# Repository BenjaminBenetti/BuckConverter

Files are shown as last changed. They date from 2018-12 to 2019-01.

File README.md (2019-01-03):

# BuckConverter
Home made buck converter with Arduino. Can provide switching between 0-30v (cannot provide more voltage than input source). Max input power is 30v. If not external
power is supplied (through Arduino USB jack) minimum voltage of 6 volts required to power Arduino. Max amperage is unknown
but be careful as this unit can get very hot (no joke it can burn down your house). any thing under 2 amps ought to be ok.

## Hardware Requirments
  - 3d Printer, to build the case.
  - 1x 7 segment 4 digit display
  - 1x Arduino nano (any Atmega 48P/88P/168P or 328P AVR MCU)
  - 1x inductor
  - 1x 1000 uF capacitor
  - 1x P type Mosfet
  - 5x NPN transistor
  - 2x tact switch
  - 1x diode
  - 2x 10k Ohm  resistor
  - 4x 5.1k Ohm resistor
  - 1x 2K Ohm   resistor
  - 1x 1K Ohm   resistor
  - 2x 330 Ohm  resistor
  - 1x 100 Ohm  resistor

## Hardware Build

with all the hardware in hand you should be able to build the circuits in the /Hardware folder:
- [Buck Converter circuit](https://github.com/CanadianCommander/BuckConverter/blob/master/Hardware/BuckConverterCircuit.pdf)
- [User Interface circuit](https://github.com/CanadianCommander/BuckConverter/blob/master/Hardware/UserInterfaceCircuit.pdf)

After that print out the case with:
- [Case Top](https://github.com/CanadianCommander/BuckConverter/blob/master/Hardware/BuckConverterTop.stl)
- [Case Bottom](https://github.com/CanadianCommander/BuckConverter/blob/master/Hardware/BuckConverterBottom.stl)

Now sandwich all the electronics in to the case and you should end up with some thing similar to [this](https://github.com/CanadianCommander/BuckConverter/blob/master/Hardware/BuckConverterFull.stl)

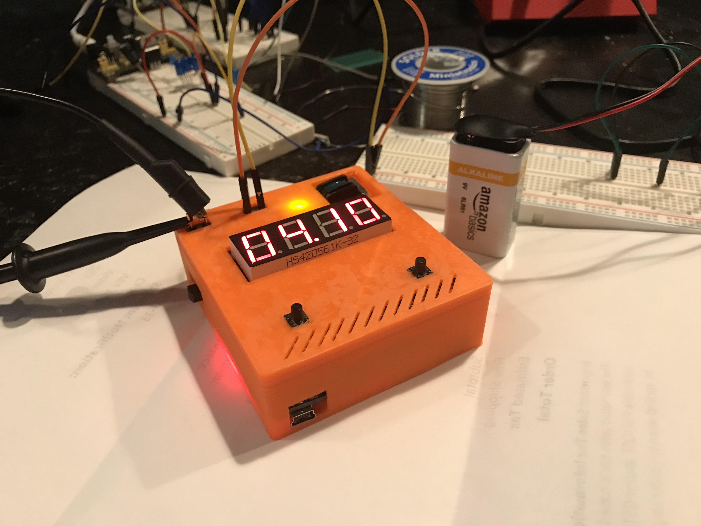
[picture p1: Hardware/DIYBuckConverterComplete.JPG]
DYI Buck Converter


## Code Build
- download repo.
- install [arduion make](https://github.com/sudar/Arduino-Makefile)
- if necessary edit the Makefile (/src/Makefile) to reflect your configuration
- then `make upload` to build and upload the code to your board.
- enjoy your buck converter!

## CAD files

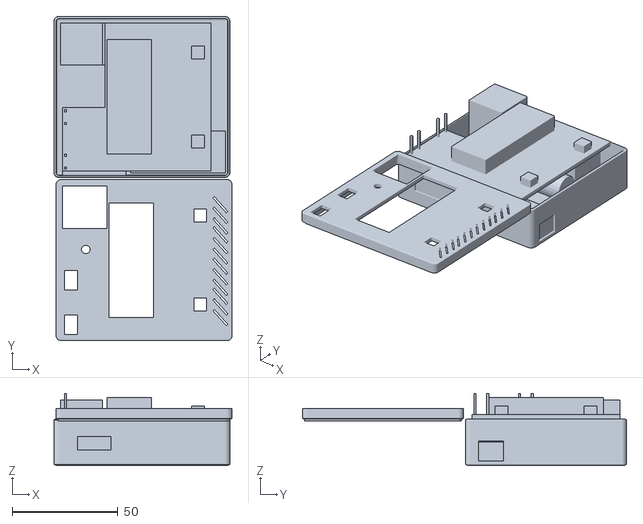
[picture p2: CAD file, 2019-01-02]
Hardware/BuckConverterFull.stl
84.0 x 153.0 x 34.0

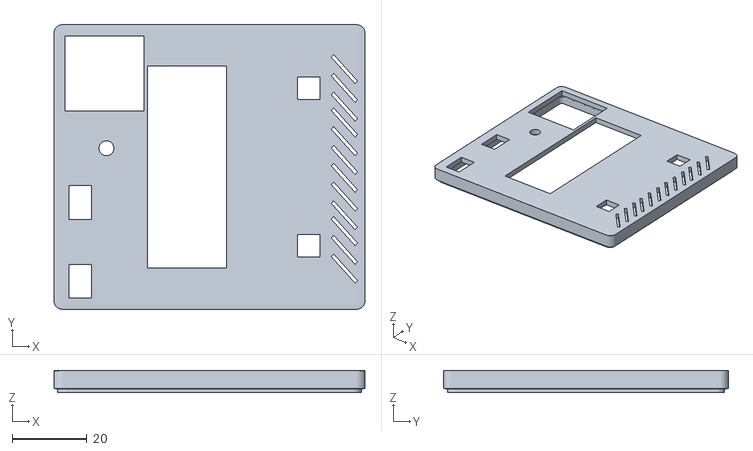
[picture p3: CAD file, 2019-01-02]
Hardware/BuckConverterTop.stl
83.0 x 76.0 x 6.00

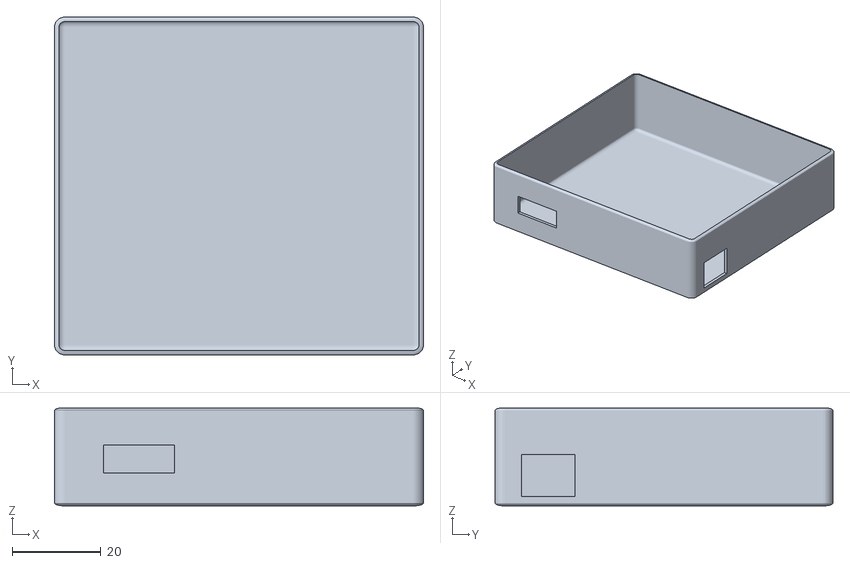
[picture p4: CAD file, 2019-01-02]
Hardware/BuckConverterBottom.stl
83.0 x 76.0 x 22.0

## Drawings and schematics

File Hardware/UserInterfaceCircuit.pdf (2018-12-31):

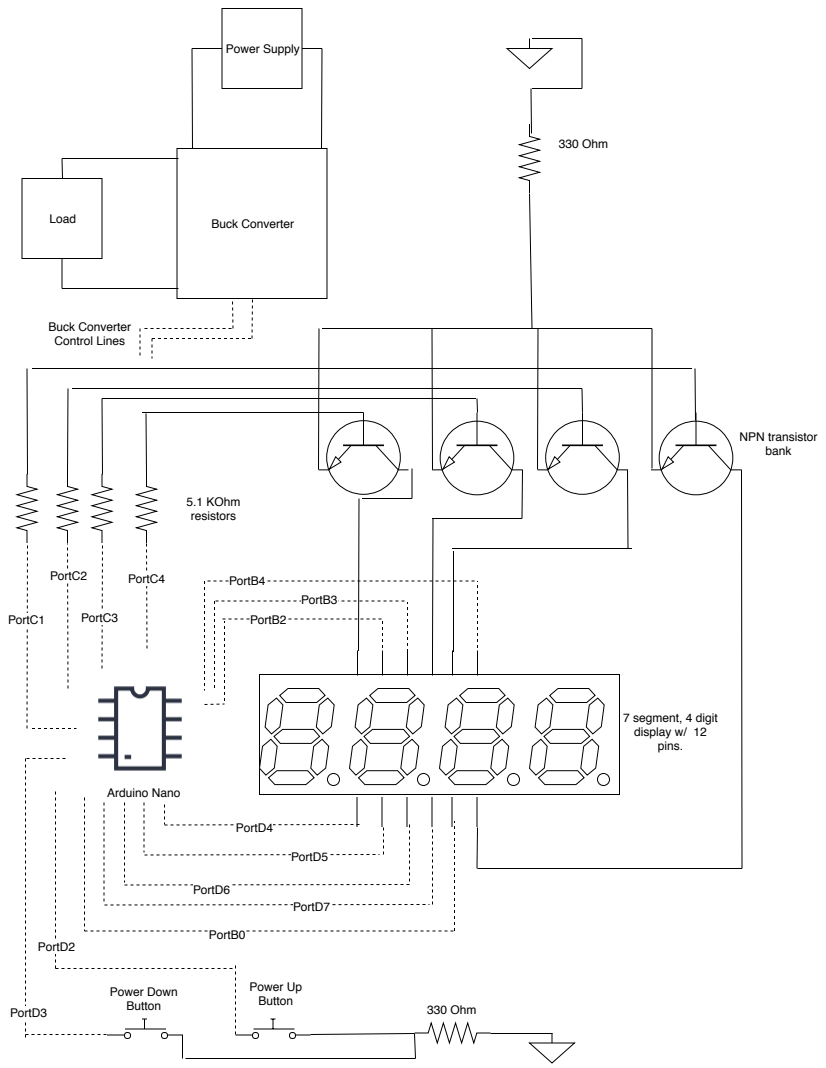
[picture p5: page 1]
Buck Converter; Power Supply; Load; Buck Converter Control Lines; Arduino Nano; PortD4; PortD5; PortD6; PortD7; PortB0; PortB2; PortB3; PortB4; NPN transistor bank; 330 Ohm; 5.1 KOhm resistors; 7 segment, 4 digit display w/ 12 pins.; PortC1; PortC2; PortC3; PortC4; Power Down Button; Power Up Button; PortD2; PortD3

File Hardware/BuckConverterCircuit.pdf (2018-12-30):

+ | -

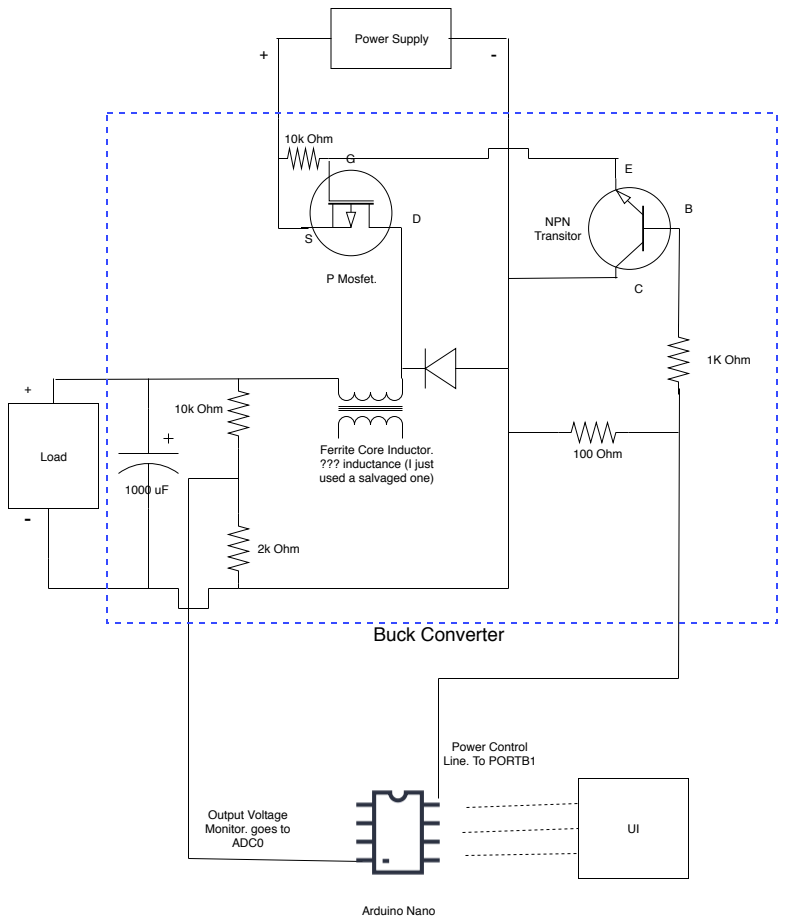
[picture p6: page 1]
P Mosfet.; 10k Ohm; Load; Power Supply; Arduino Nano; 2k Ohm; 1K Ohm; 100 Ohm; Power Control Line. To PORTB1; Buck Converter; NPN Transitor

Ferrite Core Inductor.
??? inductance (I just
used a salvaged one)

Output Voltage
Monitor. goes to
ADC0

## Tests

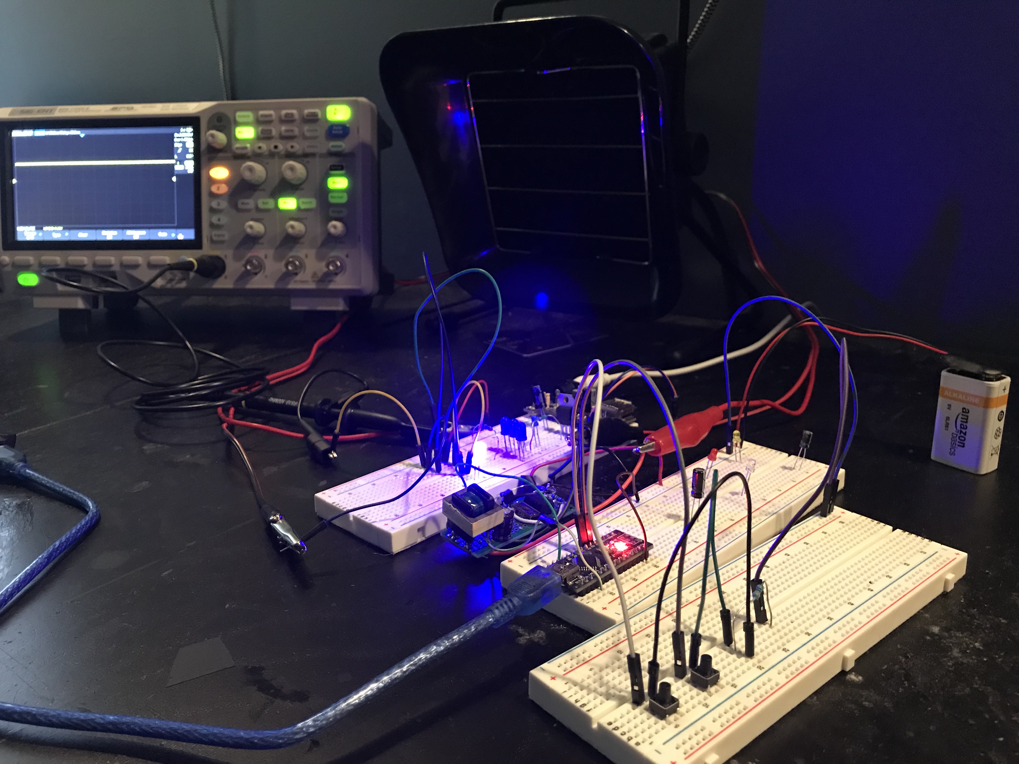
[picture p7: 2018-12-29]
Hardware/testing_the_unit.JPG

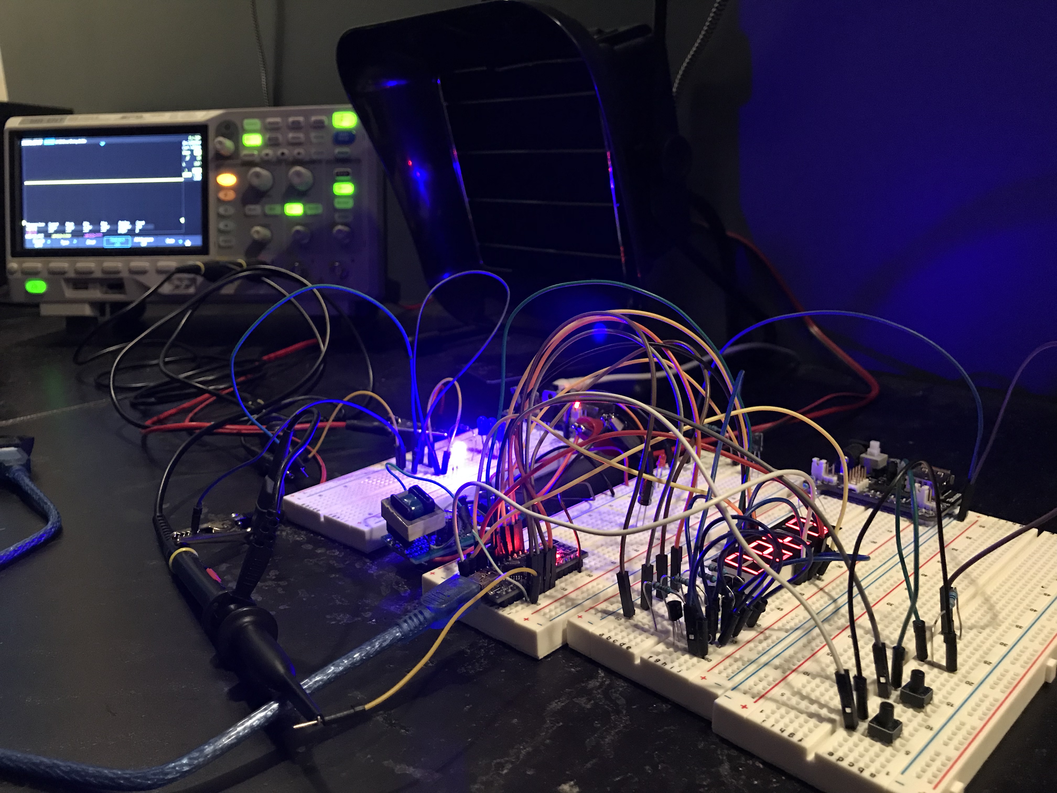
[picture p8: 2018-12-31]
Hardware/testing_uint_with_display.JPG

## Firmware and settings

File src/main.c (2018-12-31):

#include <avr/io.h>
#include <avr/interrupt.h>
#include <stdint.h>
#include <stdbool.h>
#include <string.h>
#include <math.h>

#include "ADC.h"
#include "PWM.h"
#include "UI.h"
#include "EEPROM.h"
#include "display.h"

#define PWR_TARGET_EEPROM_ADDR 1
#define PWR_TARGET_EEPROM_MARKER 0b11101010

// find the address of the power target in EEPROM.
uint16_t findPowerTargetInEEPROM(){
  uint16_t addr = searchEEPROM(PWR_TARGET_EEPROM_MARKER, 1, EEPROM_SIZE);
  if (addr == 0){
    return 1;
  }
  return addr;
}

//save power target to EEPROM at a rolling address to extend EEPROM life.
// minimum EEPROM life with the rotation method is 15,000,000 writes. (button presses in this case).
uint16_t savePowerTarget(uint16_t pwrTarget, uint16_t addr){
  uint16_t newAddr = (addr + 3) % (EEPROM_SIZE - 3);
  if (newAddr == 0) {
    newAddr ++;
  }
  //clear old address
  clearEEPROM(0, 3, addr);

  //write to new address
  uint8_t marker = PWR_TARGET_EEPROM_MARKER;
  writeEEPROM(&marker, 1, newAddr);
  writeEEPROM((uint8_t*)&pwrTarget, 2, newAddr + 1);

  return newAddr;
}

//load power target from EEPROM
uint16_t loadPowerTarget(uint16_t addr){
  uint16_t out;
  readEEPROM((uint8_t*)&out, 2, addr + 1);
  return out;
}

uint16_t calcPWMUpdate(uint16_t v, uint16_t vt){
  // "always 1" seems the best method of the ones I'v tried. perhaps some thing better
  // here in the future?
  return 1;
}

void updateDisplay();

// display vars
uint8_t displayDigits[4];
int displayIndex = 0;

// power regulation vars
uint16_t currPWM = 0;
uint16_t oldPowerTarget = 0;

uint16_t pwrTargetStorageAddress = 0;

// calculated based on voltage divider circuit
#define VOLTAGE_DIVIDER_COMPENSATION_VALUE 30.0f

void checkNSwitch() {
  uint16_t currVoltage = getADCSample();
  uint16_t currTarget = getPowerTarget();

  // update display and save new value if power target has changed.
  if (currTarget != oldPowerTarget) {
    oldPowerTarget = currTarget;
    pwrTargetStorageAddress = savePowerTarget(currTarget, pwrTargetStorageAddress);
    numToSegmentList(displayDigits, VOLTAGE_DIVIDER_COMPENSATION_VALUE * ((float)getPowerTarget() / 1024.0f), -2);
  }

  if (currVoltage < currTarget) {
    uint16_t update = calcPWMUpdate(currVoltage, currTarget);
    if (currPWM + update <= 0x3ff){
      currPWM += update;
    } else {
      currPWM = 0x3ff;
    }
    setDutyCycle(currPWM);
  } else {
    uint16_t update = calcPWMUpdate(currVoltage, currTarget);
    if ((int)currPWM - (int)update >= 0){
      currPWM -= update;
    } else {
      currPWM = 0;
    }
    setDutyCycle(currPWM);
  }
  updateDisplay();
}

void updateDisplay(){
    clearAllSegments();
    setDigit(displayIndex);
    setSegment(displayDigits[displayIndex]);
    displayIndex = (displayIndex + 1) % 4;
}

void setup() {
  initADC();
  initPWM();
  initUI();
  initDisplay();
  if (!isEEPROMContentValid()){
    initEEPROM();
  }

  sampleADCFreeRun(0x0);
  pwrTargetStorageAddress = findPowerTargetInEEPROM();
  oldPowerTarget = loadPowerTarget(pwrTargetStorageAddress);
  setPowerTarget(oldPowerTarget);
  numToSegmentList(displayDigits, VOLTAGE_DIVIDER_COMPENSATION_VALUE * ((float)getPowerTarget() / 1024.0f), -2);

  sei();
}

void loop(){
  checkNSwitch();
}

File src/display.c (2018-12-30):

#include "display.h"

#include <avr/io.h>
#include <math.h>
#include <stdlib.h>

// seven segment display setters
#define SET_DISPLAY_E()   PORTD |= (1 << PORTD4)
#define SET_DISPLAY_D()   PORTD |= (1 << PORTD5)
#define SET_DISPLAY_DP()  PORTD |= (1 << PORTD6)
#define SET_DISPLAY_C()   PORTD |= (1 << PORTD7)
#define SET_DISPLAY_G()   PORTB |= (1 << PORTB0)
#define SET_DISPLAY_A()   PORTB |= (1 << PORTB2)
#define SET_DISPLAY_F()   PORTB |= (1 << PORTB3)
#define SET_DISPLAY_B()   PORTB |= (1 << PORTB4)
#define CLEAR_DISPLAY_E()   PORTD &= ~(1 << PORTD4)
#define CLEAR_DISPLAY_D()   PORTD &= ~(1 << PORTD5)
#define CLEAR_DISPLAY_DP()  PORTD &= ~(1 << PORTD6)
#define CLEAR_DISPLAY_C()   PORTD &= ~(1 << PORTD7)
#define CLEAR_DISPLAY_G()   PORTB &= ~(1 << PORTB0)
#define CLEAR_DISPLAY_A()   PORTB &= ~(1 << PORTB2)
#define CLEAR_DISPLAY_F()   PORTB &= ~(1 << PORTB3)
#define CLEAR_DISPLAY_B()   PORTB &= ~(1 << PORTB4)

// seven segment display enablers
#define ENABLE_DISPLAY_E()   DDRD |= (1 << PORTD4)
#define ENABLE_DISPLAY_D()   DDRD |= (1 << PORTD5)
#define ENABLE_DISPLAY_DP()  DDRD |= (1 << PORTD6)
#define ENABLE_DISPLAY_C()   DDRD |= (1 << PORTD7)
#define ENABLE_DISPLAY_G()   DDRB |= (1 << PORTB0)
#define ENABLE_DISPLAY_A()   DDRB |= (1 << PORTB2)
#define ENABLE_DISPLAY_F()   DDRB |= (1 << PORTB3)
#define ENABLE_DISPLAY_B()   DDRB |= (1 << PORTB4)

//digit selector setters (note, the intentional clear of other digits in each selector)
#define SELECT_DISPLAY_DIG0() PORTC = (1 << PORTC1)
#define SELECT_DISPLAY_DIG1() PORTC = (1 << PORTC2)
#define SELECT_DISPLAY_DIG2() PORTC = (1 << PORTC3)
#define SELECT_DISPLAY_DIG3() PORTC = (1 << PORTC4)

// clear all display digits
#define CLEAR_DISPLAY_DIG_ALL() PORTC = 0x0

// digit selector enablers
#define ENABLE_DISPLAY_DIG0() DDRC |= (1 << PORTC1)
#define ENABLE_DISPLAY_DIG1() DDRC |= (1 << PORTC2)
#define ENABLE_DISPLAY_DIG2() DDRC |= (1 << PORTC3)
#define ENABLE_DISPLAY_DIG3() DDRC |= (1 << PORTC4)

//initialize the 7 segment display
void initDisplay() {
  //segments
  ENABLE_DISPLAY_E();
  ENABLE_DISPLAY_D();
  ENABLE_DISPLAY_DP();
  ENABLE_DISPLAY_C();
  ENABLE_DISPLAY_G();
  ENABLE_DISPLAY_A();
  ENABLE_DISPLAY_F();
  ENABLE_DISPLAY_B();

  //digit selectors
  ENABLE_DISPLAY_DIG0();
  ENABLE_DISPLAY_DIG1();
  ENABLE_DISPLAY_DIG2();
  ENABLE_DISPLAY_DIG3();
}

// set a segment of the 7 segment display.
void setSegment(uint8_t seg){
  if (seg & DISPLAY_A) {
    SET_DISPLAY_A();
  }
  if (seg & DISPLAY_B) {
    SET_DISPLAY_B();
  }
  if (seg & DISPLAY_C) {
    SET_DISPLAY_C();
  }
  if (seg & DISPLAY_D) {
    SET_DISPLAY_D();
  }
  if (seg & DISPLAY_E) {
    SET_DISPLAY_E();
  }
  if (seg & DISPLAY_F) {
    SET_DISPLAY_F();
  }
  if (seg & DISPLAY_G) {
    SET_DISPLAY_G();
  }
  if (seg & DISPLAY_DP) {
    SET_DISPLAY_DP();
  }
}

// clear a segment of the 7 segment display.
void clearSegment(uint8_t seg){
  if (seg & DISPLAY_A) {
    CLEAR_DISPLAY_A();
  }
  if (seg & DISPLAY_B) {
    CLEAR_DISPLAY_B();
  }
  if (seg & DISPLAY_C) {
    CLEAR_DISPLAY_C();
  }
  if (seg & DISPLAY_D) {
    CLEAR_DISPLAY_D();
  }
  if (seg & DISPLAY_E) {
    CLEAR_DISPLAY_E();
  }
  if (seg & DISPLAY_F) {
    CLEAR_DISPLAY_F();
  }
  if (seg & DISPLAY_G) {
    CLEAR_DISPLAY_G();
  }
  if (seg & DISPLAY_DP) {
    CLEAR_DISPLAY_DP();
  }
}

void clearAllSegments() {
  clearSegment(DISPLAY_A);
  clearSegment(DISPLAY_B);
  clearSegment(DISPLAY_C);
  clearSegment(DISPLAY_D);
  clearSegment(DISPLAY_E);
  clearSegment(DISPLAY_F);
  clearSegment(DISPLAY_G);
  clearSegment(DISPLAY_DP);
}

// set the digit of the display (clears others)
void setDigit(uint8_t digit){
  switch (digit) {
    case DISPLAY_DIG0:
      SELECT_DISPLAY_DIG0();
      break;
    case DISPLAY_DIG1:
      SELECT_DISPLAY_DIG1();
      break;
    case DISPLAY_DIG2:
      SELECT_DISPLAY_DIG2();
      break;
    case DISPLAY_DIG3:
      SELECT_DISPLAY_DIG3();
      break;
  }
}

void clearAllDigits() {
  CLEAR_DISPLAY_DIG_ALL();
}


// convert number in range [0 - 9] to segment bitmask
uint8_t numToSegment(uint8_t num){
  switch (num) {
    case 0:
      return DISPLAY_A | DISPLAY_B | DISPLAY_F | DISPLAY_E | DISPLAY_C | DISPLAY_D;
    case 1:
      return DISPLAY_B | DISPLAY_C;
    case 2:
      return DISPLAY_A | DISPLAY_B | DISPLAY_G | DISPLAY_E | DISPLAY_D;
    case 3:
      return DISPLAY_A | DISPLAY_B | DISPLAY_G | DISPLAY_C | DISPLAY_D;
    case 4:
      return DISPLAY_F | DISPLAY_G | DISPLAY_B | DISPLAY_C;
    case 5:
      return DISPLAY_A | DISPLAY_F | DISPLAY_G | DISPLAY_C | DISPLAY_D;
    case 6:
      return DISPLAY_A | DISPLAY_F | DISPLAY_G | DISPLAY_C | DISPLAY_D | DISPLAY_E;
    case 7:
      return DISPLAY_A | DISPLAY_B | DISPLAY_C;
    case 8:
      return DISPLAY_A | DISPLAY_B | DISPLAY_F | DISPLAY_G | DISPLAY_E | DISPLAY_C | DISPLAY_D;
    case 9:
      return DISPLAY_A | DISPLAY_F | DISPLAY_B | DISPLAY_G | DISPLAY_C | DISPLAY_D;
  }
  return DISPLAY_NONE;
}

// like floor but rounds up when value is really close to upper integer
#define QUANTIZATION_CLOSE_THRESH 0.001
uint16_t quantizationErrorAdjustedFloor(double val) {
  if (fabs(val - ceil(val)) <= QUANTIZATION_CLOSE_THRESH){
    return ceil(val);
  } else {
    return floor(val);
  }
}


/*
  convert number num. to a list of 4 numbers. these numbers are the codes
  to illuminate the 7 segment display for digit 0 - 3.
  param:
    - [lst] the list of 4 numbers in to which the segment values will be placed.
    - [num] the number to convert for display
    - [expShift] decimal place shift to apply.
*/
void numToSegmentList(uint8_t * lst, float num, int expShift){
  for (int i =0; i < 4; i ++){
    uint8_t n = (uint8_t)((uint16_t)quantizationErrorAdjustedFloor(num / pow(10, i + expShift)) % 10);
    lst[i] = numToSegment(n);

    if ((i + expShift) == 0) {
      lst[i] |= DISPLAY_DP;
    }
  }
}

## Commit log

2018-12-27 init commit. + code for a good(ish) buck converter.
2018-12-28 BitBang -> PWM. + change from bit bang to phase correct 10bit PWM. This change produces a much smother voltage graph at higher input power.
2018-12-29 Wiring Diagram for buck converter. + circuit drawing of the buck converter circuit.
2018-12-29 Organization++ + organize src files in their own folder and split functionality out of the main file in to sub files. + update capacitance of CAP in buck converter diagram to 1000 uF -> better perfor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
2018-12-29 UI. + voltage target is now controllable using pull down buttons attached to INT0 and INT1. i.e. PORTD2 and PORTD3 (pin 2 and pin 3). + remove sei/cli calls from interrupts as the avr chip does this 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
2018-12-30 Voltage target display. + add display controlling code for 7 segment 4 digit display. This display shows the user the current voltage target. The user uses the two tact switches to update the target.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
2018-12-30 update readme. + Max input voltage changed from 18v to 30v.
2018-12-31 Persist power setting across power cycles + power target is now automatically saved to EEPROM so that it can be saved between power cycles. The EEPROM storage is rotated giving the unit a life of 15 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
2018-12-31 User Interface Hardware Circuit diagram. + new diagram detailing how to build the user interface circuit. + added source files for the diagrams so they can be edited later. to open them just go to, h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
2018-12-31 Brown out EEPROM corruption fix. + Some times at power up the unit was losing its stored power target value. This was caused (I think) by my crappy USB cable which has a really bad connection. Just t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
    [main.c]
2019-01-02 Add 3d printing models. + add models for 3d printing of case. + update README to be more descriptive and reference new models
    [BuckConverterBottom.stl, BuckConverterFull.stl, BuckConverterTop.stl]
